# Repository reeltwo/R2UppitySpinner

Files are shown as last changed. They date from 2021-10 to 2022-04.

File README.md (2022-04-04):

# R2 Uppity Spinner

This is the sketch for the R2 Uppity Spinner. It depends on the Reeltwo library. You can download the latest release of the Reeltwo library here: https://github.com/reeltwo/Reeltwo/releases

Uppity Spinner (https://vimeo.com/558277516)

Default baud rate is 9600 baud and the default I2C address is 32 (0x20). Both can be changed using the configuration commands below.

After installing your board you should run the `#PSC` calibration command.

If you want a snappy hyper caffinated periscope you should use a 6V lifter motor. If you want a slower more deliberate periscope you should use a 12V lifter motor.

# Assembling R2 Uppity Spinner PCB Part 1
Part1 (https://www.youtube.com/watch?v=x4_3irdV4C8)

# Assembling R2 Uppity Spinner PCB Part 2
Part2 (https://www.youtube.com/watch?v=MdSRJsYx1T8)

## Configure commands

`#PSC`:
Calibration routine. Will store results in EEPROM if successful
*Examples*:

    #PSC

`#PZERO`:
Erase all stored sequences from EEPROM
*Examples*:

    #PZERO

`#PL`:
List all stored sequences
*Examples*:

    #PL

`#PD`[number]:
Delete numbered sequence from EEPROM
*Examples*:

    #PD0 (delete sequence 0)

`#PS`[number]:seq
Store specified sequence (seq) as number in EEPROM.
*Examples*:

	#PS1:H                        (periscope down)
	#PS2:P100                     (periscope up)
	#PS3:P100:L5:R30              (search light counter-clockwise)
	#PS4:P100,100:L7:M,80,80,2,4  (random fast)
	#PS5:P100:L7:M,50,40,5,5      (random slow)
	#PS6:A0                       (face forward)
	#PS7:P100:L5:R-30             (search light clockwise)
	#PS8:H:P50:W2:P85,35:A90,25:W2:A270,20,100:W2:P100,100:L5:R50:W4:H    (sneaky periscope)
	#PS0:H:L0:P100,5:W2:P50:W2:P85,35:A90,25:W2:A270,20,100:W2:P100,100:L5:R50:W4:H

`#PBAUD`[baudrate]
Change system baudrate. Settings will be stored in EEPROM and take affect once the board is reset.
*Examples*:

	#PBAUD9600               (set baud rate to 9600)

`#PI2C`[address]
Change system I2C address. Settings will be stored in EEPROM and take affect once the board is reset.
*Examples*:

	#PI2C128                 (set I2C address to 128)

`#PR`
Enable/disable rotary unit. This will reboot the board. The setting will persist between reboots.
*Examples*:

	#PR (toggle rotary unit on/off)

`#PNCL`
Set lifter limit switch to normally closed. Default setting.
*Examples*:

	#PNCL (lifter limit normally closed)

`#PNOL`
Set lifter limit switch to normally open.
*Examples*:

	#PNOL (lifter limit normally open)

`#PNCR`
Set rotary limit switch to normally closed. Default setting.
*Examples*:

	#PNCL (rotary limit normally closed)

`#PNOR`
Set rotary limit switch to normally open.
*Examples*:

	#PNOR (rotary limit normally open)

Lifter commands
===============

A lifter command starts with ':P' followed by one of the these. Multiple commands can be issued seperated by a colon. Only the first command needs to be prefixed with 'P':

	:PP100:W2:P0

Would raise the periscope. Wait 2 seconds. Lower the periscope. Separately the commnads would be:

	:PP100
	:PW2
	:PP0

### Play stored sequence

`S`[number]:
Sequences can be stored using #PS
*Examples*:

    #PS0:H:L0:P100,5:W2:P50,25:W2:P85,35:A90,20:W2:A270,20,100:W2:P100,100:L5:R50:W4:H

### Wait number of seconds
`W`[R]seconds:
Wait for specified number of seconds. If 'R' is specified it will randomize the wait time in the range of 1..seconds. 'seconds' is a number between 1 and 600.
*Examples*:

	:PW2    (wait 2 seconds before executing next sequence)
	:PWR    (wait random 1-6 seconds)
	:PWR10  (wait random 1-10 seconds)

### Light kit sequence
`L`number:
Light kit sequence where number is in the range 0..7

`0`: Full Cycle (default): This routine will randomly select the LED color, pattern, and speed for a random period of time.
    
`1`: Off: This setting turns ALL lights OFF. I added this to allow a microcontroller to turn off the lights without having to kill the supply power.
    
`2`: Obi Wan: The Top LED’s flash Blue, the Side LED’s are Blue, and the Main White LED’s are Random.
    
`3`: Yoda: The Top LED’s and Side LED’s fade Green On and Off.
    
`4`: Sith: The Top LED’s and Side LED’s flash Red.
    
`5`: Search Light: All LED’s are White, the Center Bright LED is ON.
    
`6`: Dagobah: This is the most screen accurate mode. The Main White LED’s are ON, the side LED’s are White, the Lower  Rectangular Red LED’s are All On, and the Rear LED’s are Blinking Red.
    
`7`: Sparkle: All White LED’s randomly Flash
    
*Examples*:

    :PL0    (full cycle)
    :PL1    (off)

### Home
`H`[speed]:
Rotates the periscope into the home position and lowers the lifter. Will retry once if rotary ends up not in home position.
*Examples*:

	:PH     (go home at minimum power)
	:PH50   (go home at 50% speed)
	:PH100  (go home at 100% speed)

### Rotate scope relative degrees
`D`[R]:
Rotate scope random relative degrees
*Examples*:

	:PDR

`D`[degrees]:
Rotate scope relative degrees positive for counter clockwise and negative for clockwise
*Examples*:

	:PD90       (rotate periscope relative 90 degrees counter clockwise)
	:PD-90      (rotate periscope relative 90 degrees clockwise)

### Rotate scope absolute degrees
`A`[R][,speed][,maxspeed]:
Rotate scope random absolute degrees
*Examples*:

	:PAR

`A`[degrees][,speed][,maxspeed]:
Rotate scope to absolute position degrees. Positive for clockwise and negative for counter clockwise. Optionally specify the speed percentage and maximum speed percentage. By default the speed used is minimum rotary power (20%). The maximum speed defaults to the same value as speed if omitted.
*Examples*:

	:PA90        (rotate periscope to 90 degrees clockwise)
	:PA270       (rotate periscope to 270 degrees clockwise)
	:PA-90       (rotate periscope to 270 degrees clockwise)
	:PA0         (rotate periscope to home position)
	:PA90,20,100 (rotate periscope to 90 degrees starting at 20% speed increasing to 100%)
	             (will mostly likely overshoot target)

### Rotate scope continously
`R`[speed]:
Spin rotary scope at specified speed percentage
*Examples*:

	:PR30       (spin periscope at 30% speed counter clockwise)
	:PR-30      (spin periscope at 30% speed clockwise)

`R`[,speed]:
Lift periscope to random position.
*Examples*:

	:PPR        (random position)
	:PPR,50     (random position at 50% speed)

### Raise/lower periscope
`P`[position][,speed]:
Lift periscope to specified position percentage.
*Examples*:

	:PP100      (raise periscope fully)
	:PP0        (lower periscope fully)
	:PP50       (raise periscope halfway)
	:PP100,100  (raise periscope fully at maximum speed)

### Movement Random Continous
`M`,lifterspeed][,rotaryspeed][,mininterval][,maxinterval]:
Animate periscope continously rotate/lift.
*Examples*:

	:M,80,80,2,4  (animate lifter 80% power, rotatary random(20%-80%), minimum interval 2 seconds for a duration of 2+random(4) seconds )
	:M,50,40,5,5  (animate lifter 50% power, rotatary random(20%-40%) power, 80% minimum interval 5 seconds for a duration of 5+5 seconds )

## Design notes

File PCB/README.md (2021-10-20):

# Electronics Design

The files were created using Fusion 360, which uses a new version of the Eagle format.

- LifterPCB.brd
- LifterPCB.sch

- RotaryPCB.brd
- RotaryPCB.sch

These files were exported in Eagle v9 compatible format.

- LifterPCB_v9.brd
- LifterPBC_v9.sch

- RotaryPCB_v9.brd
- RotaryPCB_v9.sch

This version uses thicker traces and adds a copper pour. The lifter board is a four layer board. The order of the connection pins on the rotary has changed. Do NOT use the same cable as the older board. The order was changed to allow using a silicone ribbon cable and this crimp connector:

https://www.mouser.com/ProductDetail/571-2-1761607-3

The 10 Wire silicone cable:
https://www.adafruit.com/product/3890

The dual row IDC female connectors:
https://www.amazon.com/gp/product/B07S1NFG4S

If you do not plan on using the ribbon cable there is no need to switch to this version of the lifter.

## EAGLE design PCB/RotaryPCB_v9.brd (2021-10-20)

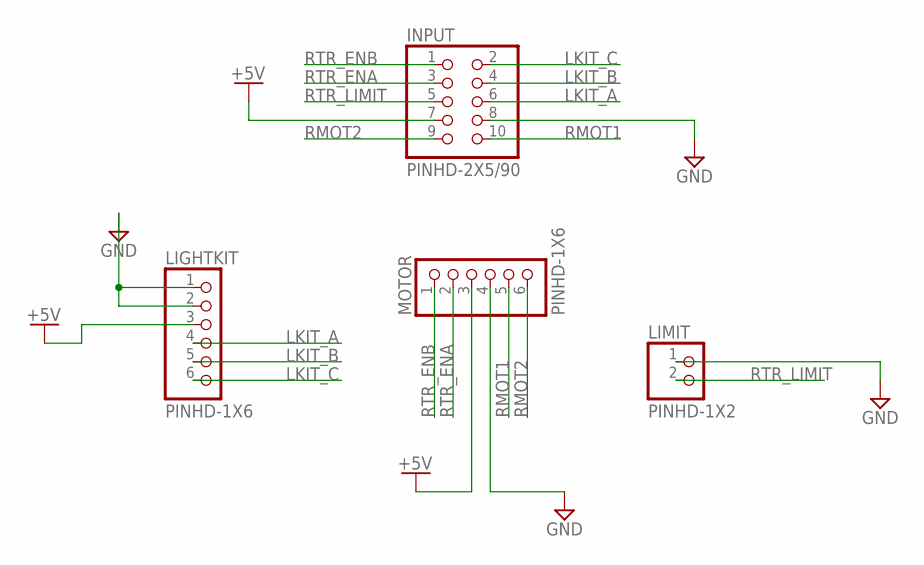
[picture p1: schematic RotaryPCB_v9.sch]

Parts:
INPUT: PINHD-2X5/90; 2X05/90
LIGHTKIT: PINHD-1X6; 1X06
LIMIT: PINHD-1X2; 1X02
MOTOR: PINHD-1X6; 1X06

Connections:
+5V: INPUT.7, LIGHTKIT.3, MOTOR.3
GND: INPUT.8, LIGHTKIT.1, LIGHTKIT.2, LIMIT.1, MOTOR.4
LKIT_A: INPUT.6, LIGHTKIT.4
LKIT_B: INPUT.4, LIGHTKIT.5
LKIT_C: INPUT.2, LIGHTKIT.6
RMOT1: INPUT.10, MOTOR.5
RMOT2: INPUT.9, MOTOR.6
RTR_ENA: INPUT.3, MOTOR.2
RTR_ENB: INPUT.1, MOTOR.1
RTR_LIMIT: INPUT.5, LIMIT.2

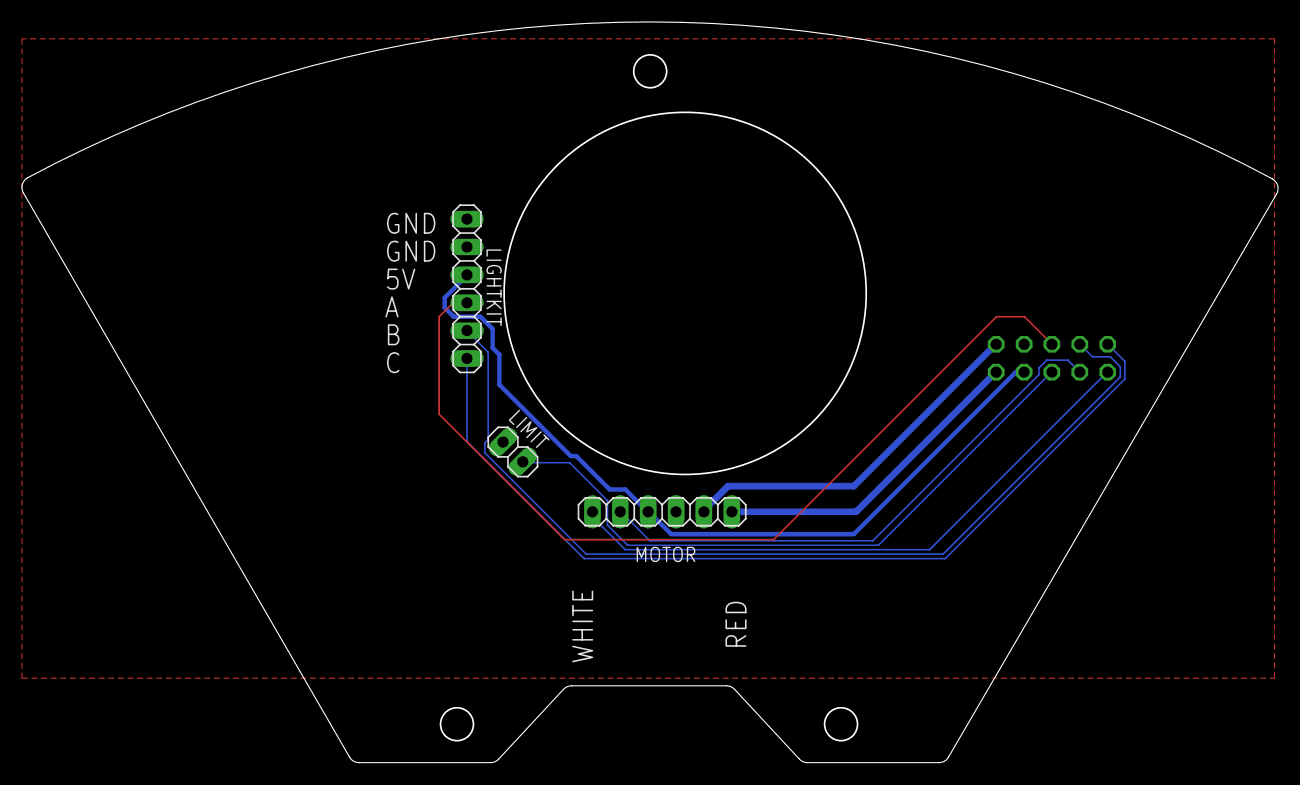
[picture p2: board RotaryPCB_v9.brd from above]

Board: 2 copper layers, 114.5 x 67.5 mm, 4 parts (1 on the bottom side), 10 nets.

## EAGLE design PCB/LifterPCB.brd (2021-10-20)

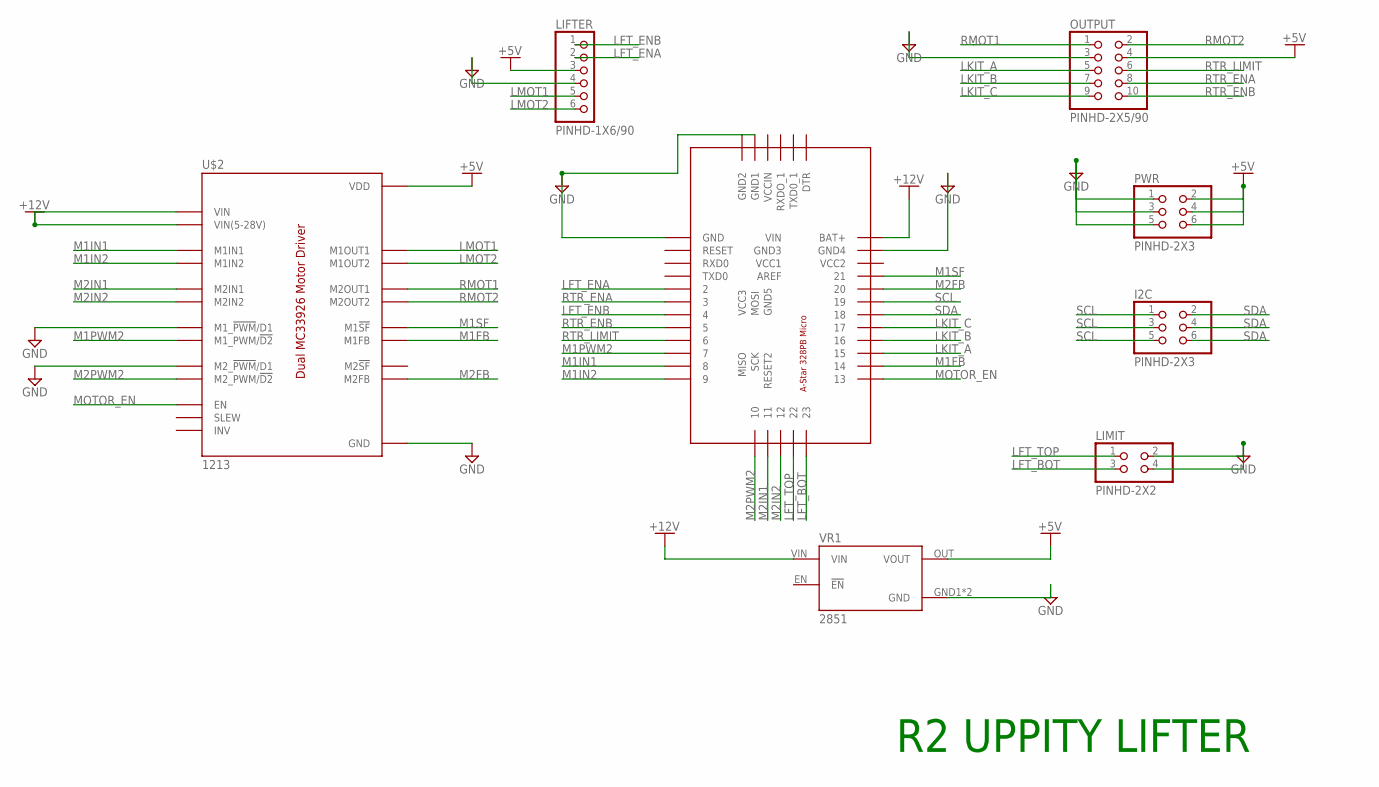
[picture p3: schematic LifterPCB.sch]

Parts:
I2C: PINHD-2X3; 2X03
LIFTER: PINHD-1X6/90; 1X06/90
LIMIT: PINHD-2X2; 2X02
OUTPUT: PINHD-2X5/90; 2X05/90
PWR: PINHD-2X3; 2X03
U$1: POLOLU3161
U$2: 1213
VR1: 2851; VREG_2851

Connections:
+5V: LIFTER.3, OUTPUT.4, PWR.2, PWR.4, PWR.6, U$2.VDD, U$2.VDD$1 (VDD), U$2.VDD$2 (VDD), U$2.VDD$3 (VDD), U$2.VDD$4 (VDD), U$2.VDD$5 (VDD), VR1.OUT (VOUT)
+12V: U$1.BAT+, U$2.MVIN (VIN(5-28V)), U$2.VIN, VR1.VIN
GND: LIFTER.4, LIMIT.2, LIMIT.4, OUTPUT.3, PWR.1, PWR.3, PWR.5, U$1.GND2 (GND4), U$1.GND4 (GND2), U$1.GND5 (GND1), U$1.GND6 (GND), U$2.GND, U$2.GND$1 (GND), U$2.GND$2 (GND), U$2.M1PWM1 (M1_!PWM!/D1), U$2.M2PWM1 (M2_!PWM!/D1), U$2.MGND (GND), VR1.GND1 (GND), VR1.GND2 (GND)
LFT_BOT: LIMIT.3, U$1.23
LFT_ENA: LIFTER.2, U$1.2
LFT_ENB: LIFTER.1, U$1.4
LFT_TOP: LIMIT.1, U$1.22
LKIT_A: OUTPUT.5, U$1.15
LKIT_B: OUTPUT.7, U$1.16
LKIT_C: OUTPUT.9, U$1.17
LMOT1: LIFTER.5, U$2.M1OUT1
LMOT2: LIFTER.6, U$2.M1OUT2
M1FB: U$1.14, U$2.M1FB
M1IN1: U$1.8, U$2.M1IN1
M1IN2: U$1.9, U$2.M1IN2
M1PWM2: U$1.7, U$2.M1PWM2 (M1_PWM/!D2)
M1SF: U$1.21, U$2.M1SF (M1!SF)
M2FB: U$1.20, U$2.M2FB
M2IN1: U$1.11$1 (11), U$2.M2IN1
M2IN2: U$1.12$1 (12), U$2.M2IN2
M2PWM2: U$1.10, U$2.M2PWM2 (M2_PWM/!D2)
MOTOR_EN: U$1.13$1 (13), U$2.EN
RMOT1: OUTPUT.1, U$2.M2OUT1
RMOT2: OUTPUT.2, U$2.M2OUT2
RTR_ENA: OUTPUT.8, U$1.3
RTR_ENB: OUTPUT.10, U$1.5
RTR_LIMIT: OUTPUT.6, U$1.6
SCL: I2C.1, I2C.3, I2C.5, U$1.19
SDA: I2C.2, I2C.4, I2C.6, U$1.18

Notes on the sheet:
R2 UPPITY LIFTER

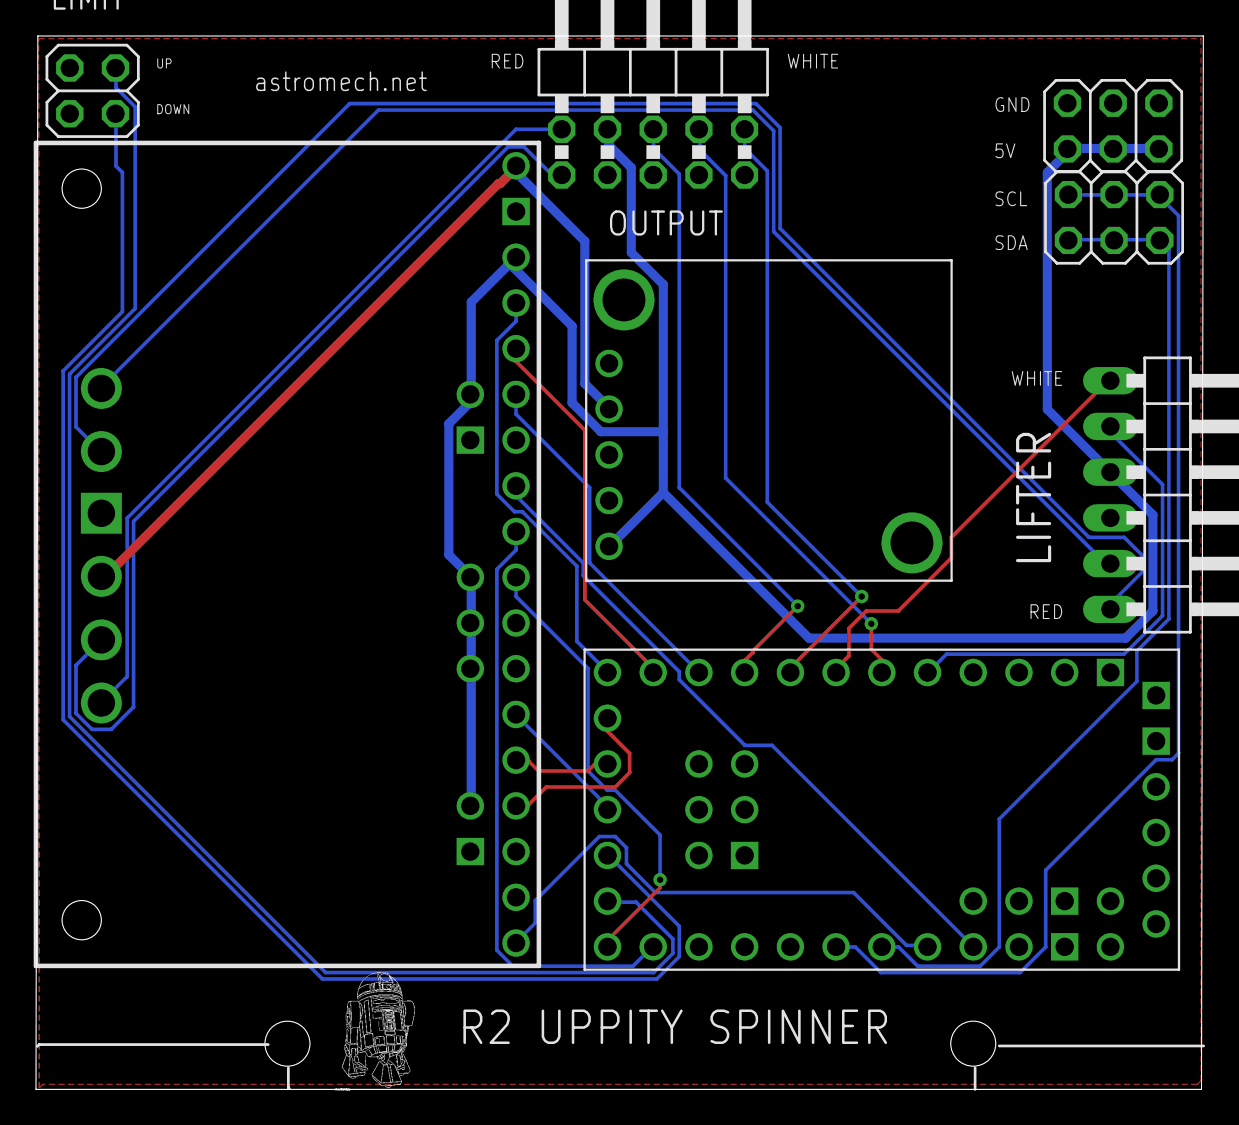
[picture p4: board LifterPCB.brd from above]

Board: 4 copper layers, 64.9 x 58.5 mm, 8 parts (0 on the bottom side), 29 nets.

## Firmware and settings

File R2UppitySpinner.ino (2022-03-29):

//#define USE_DEBUG
#include "ReelTwo.h"
#include "core/SetupEvent.h"
#include "core/Enthropy.h"

///////////////////////////////////
// CONFIGURABLE OPTIONS
///////////////////////////////////

// If debug is enabled the serial baud rate will be 57600
#define SERIAL_BAUD_RATE                    9600
#define I2C_ADDRESS                         0x20
#define CONSOLE_BUFFER_SIZE                 300
#define COMMAND_BUFFER_SIZE                 256
#define ROTARY_THROTTLE_ACCELERATION_SCALE  100
#define ROTARY_THROTTLE_DECELERATION_SCALE  20
#define ROTARY_THROTTLE_LATENCY             25
#define ROTARY_FUDGE_POSITION               5

// Default random duration of 'M' movement mode
#define MOVEMODE_MIN_DURATION               30      // minimum 30 seconds
#define MOVEMODE_MAX_DURATION               30      // random range additional 30 seconds
#define MOVEMODE_MAX_INTERVAL               5       // default interval between random commands

///////////////////////////////////
// RISKIER CONFIGURATION OPTIONS
///////////////////////////////////

// IA-Parts lifter defaults
#define LIFTER_MINIMUM_POWER        45      // 40 out of 100. Don't bother with lower values. Won't lift reliably
#define LIFTER_SEEKBOTTTOM_POWER    30      // 30 out of 100. Lower than LIFTER_MINIMUM_POWER because we are going down
#define ROTARY_MINIMUM_POWER        20      // 20 out of 100. Don't bother with lower values. Won't rotate reliably
#define LIFTER_DISTANCE             845     // default value - lifter will calibrate

// Greg Hulette’s Periscope Lifter
//#define LIFTER_MINIMUM_POWER        65      // 65 out of 100. Don't bother with lower values. Won't lift reliably
//#define LIFTER_SEEKBOTTTOM_POWER    40      // 40 out of 100. Lower than LIFTER_MINIMUM_POWER because we are going down
//#define ROTARY_MINIMUM_POWER        40      // 40 out of 100. Don't bother with lower values. Won't rotate reliably
//#define LIFTER_DISTANCE             1200     // default value 1200 - lifter will calibrate

#define ROTARY_MINIMUM_HEIGHT       LIFTER_DISTANCE/2
#define MOTOR_TIMEOUT               2000
#define OUTPUT_LIMIT_PRESCALE       3.1
#define DISTANCE_OUTPUT_SCALE       3
#define MAX_COMMANDS                100

#define EEPROM_MAGIC                0xba5eba11
#define EEPROM_CMD_MAGIC            0xf005ba11
#define EEPROM_END_TAG              0xff

///////////////////////////////////
// This option is for builders working on their own custom lifters.
// It will leave the lifter logic intact but act as if there is no rotary.
///////////////////////////////////
//#define DISABLE_ROTARY
///////////////////////////////////

#ifdef DISABLE_ROTARY
// DO NOT ENABLE THIS UNLESS YOU REMOVE THE ROTARY UNIT
#define DISABLE_SAFETY_MANEUVER
#endif

///////////////////////////////////
// --- Lifter mechanism

#define PIN_LIFTER_ENCODER_A   2
#define PIN_LIFTER_ENCODER_B   4

#define PIN_M1SF               A7
#define PIN_M2FB               A6

#define PIN_LIFTER_TOPLIMIT    23
#define PIN_LIFTER_BOTLIMIT    22

/* Lifter Motor */
#define PIN_MOTORS_EN          13   /* also BUILTIN_LED */
#define PIN_M1D2               7
#define PIN_M1PWM1             8
#define PIN_M1PWM2             9
#define PIN_M1FB               A0

///////////////////////////////////
// --- Rotary mechanism

#define PIN_ROTARY_ENCODER_A   3
#define PIN_ROTARY_ENCODER_B   5

#define PIN_ROTARY_LIMIT       6

/* Rotary Motor */
#define PIN_M2D2               10
#define PIN_M2PWM1             11
#define PIN_M2PWM2             12

//////////////////////////////
// LIGHT KIT TRI-STATE
//////////////////////////////
//   A    B    C
// OPEN OPEN OPEN  (Switch Position 0): Full Cycle (default): This routine will randomly select the LED
//                                      color, pattern, and speed for a random period of time.
// OPEN OPEN GND   (Switch Position 1): Off: This setting turns ALL lights OFF. I added this to allow a
//                                      microcontroller to turn off the lights without having to kill
//                                      the supply power.
// OPEN GND  OPEN  (Switch Position 2): Obi Wan: The Top LED’s flash Blue, the Side LED’s are Blue,
//                                      and the Main White LED’s are Random.
// OPEN GND  GND   (Switch Position 3): Yoda: The Top LED’s and Side LED’s fade Green On and Off.
// GND  OPEN OPEN  (Switch Position 4): Sith: The Top LED’s and Side LED’s flash Red.
// GND  OPEN GND   (Switch Position 5): Search Light: All LED’s are White, the Center Bright LED is ON.
// GND  GND  OPEN  (Switch Position 6): Dagobah: This is the most screen accurate mode.
//                                      The Main White LED’s are ON, the side LED’s are White, the Lower 
//                                      Rectangular Red LED’s are All On, and the Rear LED’s are Blinking Red.
// GND GND GND     (Switch Position 7): Sparkle: All White LED’s randomly Flash

#define PIN_LIGHTKIT_A         A1
#define PIN_LIGHTKIT_B         A2
#define PIN_LIGHTKIT_C         A3

///////////////////////////////////
// SDA A4
// SCL A5

#ifdef I2C_ADDRESS
#include <Wire.h>
#endif
#include <EEPROM.h>

///////////////////////////////////

#include "drive/TargetSteering.h"

///////////////////////////////////
#define ENCODER_STATUS_RATE 200 // ms (10Hz)

struct OutputLimit
{
    bool valid;
    unsigned outputLimit;
};

OutputLimit sUpLimits[100/5+1];
OutputLimit sDownLimits[100/5+1];
unsigned sMinimumPower;
unsigned sLifterDistance = LIFTER_DISTANCE;
bool sUpLimitsCalibrated;
bool sDownLimitsCalibrated;
bool sSafetyManeuver;
bool sCalibrating;
bool sDisableRotary;
uint8_t sI2CAddress = I2C_ADDRESS;
uint32_t sBaudRate = SERIAL_BAUD_RATE;
unsigned sRotaryCircleEncoderCount;

static bool sNextCommand;
static bool sProcessing;
static unsigned sPos;
static uint32_t sWaitNextSerialCommand;
static char sBuffer[CONSOLE_BUFFER_SIZE];
static bool sCmdNextCommand;
static char sCmdBuffer[COMMAND_BUFFER_SIZE];

static void runSerialCommand()
{
    sWaitNextSerialCommand = 0;
    sProcessing = true;
}

static void resetSerialCommand()
{
    sWaitNextSerialCommand = 0;
    sNextCommand = false;
    sProcessing = (sCmdBuffer[0] == ':');
    sPos = 0;
}

///////////////////////////////////

class PeriscopeLifter : public SetupEvent
{
public:
    enum
    {
        kLightKit_FullCycle = 0,
        kLightKit_Off = 1,
        kLightKit_ObiWan = 2,
        kLightKit_Yoda = 3,
        kLightKit_Sith = 4,
        kLightKit_SearchLight = 5,
        kLightKit_Dagobah = 6,
        kLightKit_Sparkle = 7
    };

    static void println()
    {
        Serial.println();
    }

    static void print(char num)
    {
        Serial.print(num);
    }

    static void print(int num)
    {
        Serial.print(num);
    }

    static void print(long num)
    {
        Serial.print(num);
    }

    static void print(unsigned int num)
    {
        Serial.print(num);
    }

    static void print(float num)
    {
        Serial.print(num);
    }

    static void print(const char* str)
    {
        Serial.print(str);
    }

    static void print(const __FlashStringHelper* str)
    {
        Serial.print(str);
    }

    static void println(char num)
    {
        Serial.println(num);
    }

    static void println(int num)
    {
        Serial.println(num);
    }

    static void println(long num)
    {
        Serial.println(num);
    }

    static void println(unsigned int num)
    {
        Serial.println(num);
    }

    static void println(float num)
    {
        Serial.println(num);
    }

    static void println(const char* str)
    {
        Serial.println(str);
    }

    static void println(const __FlashStringHelper* str)
    {
        Serial.println(str);
    }

    ///////////////////////////////////
    // Read limit switches
    ///////////////////////////////////

    static bool lifterTopLimit()
    {
        bool limit = (digitalRead(PIN_LIFTER_TOPLIMIT) == fLifterLimitSetting);
        return limit;
    }

    static bool lifterBottomLimit()
    {
        bool limit = (digitalRead(PIN_LIFTER_BOTLIMIT) == fLifterLimitSetting);
        return limit;
    }

    static long getLifterPosition()
    {
        long pos;
        cli();
        pos = encoder_lifter_ticks;
        sei();
        return pos;
    }

    ///////////////////////////////////

    static bool rotaryHomeLimit()
    {
    #ifdef DISABLE_ROTARY
        // No rotary unit. Always in home position
        return true;
    #else
        bool limit = sDisableRotary || (digitalRead(PIN_ROTARY_LIMIT) == fRotaryLimitSetting);
        return limit;
    #endif
    }

    static long getRotaryPosition()
    {
        long pos;
        cli();
        pos = encoder_rotary_ticks;
        sei();
        return pos;
    }

    ///////////////////////////////////

    static bool lifterMotorFault()
    {
        return !digitalRead(PIN_M1SF);
    }

    static int lifterMotorCurrent()
    {
        // 5V / 10bit resolution / 0.525V/A = 0.0093006 A/count ~= 93 mA/count
        return analogRead(PIN_M1FB) * 93;
    }

    static int rotaryMotorCurrent()
    {
        // 5V / 10bit resolution / 0.525V/A = 0.0093006 A/count ~= 93 mA/count
        return analogRead(PIN_M2FB) * 93;
    }

    static bool isIdle()
    {
        if (lifterBottomLimit())
        {
            if (!fMotorsEnabled ||
                fMotorsEnabledTime + MOTOR_TIMEOUT < millis())
            {
                return true;
            }
        }
        return false;
    }

    ///////////////////////////////////

    static bool motorsEnabled()
    {
        return fMotorsEnabled;
    }

    static void disableMotors()
    {
        digitalWrite(PIN_MOTORS_EN, LOW);
        digitalWrite(PIN_M1D2, LOW);
        digitalWrite(PIN_M2D2, LOW);
        fMotorsEnabled = false;
    }

    static void enableMotors()
    {
        digitalWrite(PIN_MOTORS_EN, HIGH);
        fMotorsEnabled = true;
        fMotorsEnabledTime = millis();
    }

    ///////////////////////////////////
    // Move lifter motor up/down
    ///////////////////////////////////

    static void lifterMotorMove(float throttle)
    {
        bool reverse = (throttle < 0);
        throttle = min(max(abs(throttle), 0.0f), 1.0f);

        if (throttle < 0.10)
            throttle = 0;
        if (fLifterThrottle != throttle)
        {
            enableMotors();
            if (reverse)
            {
                analogWrite(PIN_M1PWM1, 255);
                analogWrite(PIN_M1PWM2, 255 - (255 * throttle));
                fLifterThrottle = -throttle;
            }
            else
            {
                analogWrite(PIN_M1PWM1, 0);
                analogWrite(PIN_M1PWM2, 255 * throttle);
                fLifterThrottle = throttle;
            }
            digitalWrite(PIN_M1D2, HIGH);
        }
    }

    static void lifterMotorStop()
    {
        enableMotors();
        analogWrite(PIN_M1PWM1, 0);
        analogWrite(PIN_M1PWM2, 0);
        digitalWrite(PIN_M1D2, HIGH);
        fLifterThrottle = 0;
    }

    static void lifterMotorOff()
    {
        digitalWrite(PIN_M1D2, LOW);
    }

    ///////////////////////////////////

    static bool serialAbort()
    {
        if (sCalibrating && Serial.available())
        {
            DEBUG_PRINTLN("SERIAL ABORT");
            while (Serial.available())
                Serial.read();
            sCalibrating = false;
            return true;
        }
        return false;
    }

    static bool seekToPosition(float pos, float speed)
    {
        if (!ensureSafetyManeuver())
            return false;

        // ensure position is in the range of 0.0 [bottom] - 1.0 [top]
        pos = min(max(abs(pos), 0.0f), 1.0f);
        if (isRotarySpinning() || !rotaryHomeLimit())
        {
            // Cannot go below 50% if spinning or not at home position
            pos = min(max(pos, 0.5f), 1.0f);
        }
        if (speed * 100 < sMinimumPower)
            return seekToPositionSlow(pos, speed/(sMinimumPower/100.0));

        long maxlen = sLifterDistance;
        long current = getLifterPosition();
        long target_ticks = pos * maxlen;

        long distance = abs(target_ticks - current);
        TargetSteering steering(target_ticks);
        steering.setSampleTime(1);
        float minpower = (1.0f - ((float)distance / (float)maxlen)) + 0.1;
        steering.setDistanceTunings(1.0, minpower, minpower);

        float limit;
        bool success = false;
        if (target_ticks > getLifterPosition())
        {
            // seek up
            if (!getUpOutputLimit(speed, limit))
                return false;
            steering.setDistanceOutputLimits(min(distance * DISTANCE_OUTPUT_SCALE, limit));
            bool topLimit;
            LifterStatus lifterStatus;
            for (;;)
            {
                long encoder_ticks = getLifterPosition();
                topLimit = lifterTopLimit();
                if (topLimit || encoder_ticks == target_ticks || serialAbort())
                    break;
                steering.setCurrentDistance(encoder_ticks);
                lifterMotorMove(steering.getThrottle() * speed);

                if (!lifterStatus.isMoving())
                {
                    DEBUG_PRINTLN(F("ABORT"));
                    break;
                }
            }
            success = topLimit;
        }
        else
        {
            // seek down
            if (!getDownOutputLimit(speed, limit))
                return false;
            steering.setDistanceOutputLimits(min(distance * DISTANCE_OUTPUT_SCALE, limit));
            bool botLimit;
            LifterStatus lifterStatus;
            for (;;)
            {
                long encoder_ticks = getLifterPosition();
                botLimit = lifterBottomLimit();
                if (botLimit || encoder_ticks == target_ticks || serialAbort())
                    break;
                steering.setCurrentDistance(encoder_ticks);
                lifterMotorMove(steering.getThrottle() * speed);

                if (!lifterStatus.isMoving())
                {
                    DEBUG_PRINTLN(F("ABORT"));
                    break;
                }
            }
            success = botLimit;
        }
        lifterMotorStop();
        return success;
    }

    ///////////////////////////////////
    // Spin rotary motor left/right
    ///////////////////////////////////

    static bool rotaryAllowed()
    {
    #ifdef DISABLE_ROTARY
        // Rotary motion not allowed
        return false;
    #else
        return !sDisableRotary && (getLifterPosition() > ROTARY_MINIMUM_HEIGHT);
    #endif
    }

    static void rotaryMotorSpeed(float speed)
    {
        fRotarySpeed = (rotaryAllowed()) ? speed : 0;
        fRotaryEncoderLastStatus = millis();
        rotaryMotorUpdate();
    }

    static void rotaryMotorUpdate()
    {
    #ifndef DISABLE_ROTARY
        if (sDisableRotary)
            return;
        uint32_t currentMillis = millis();
        if (currentMillis - fRotaryThrottleUpdate > ROTARY_THROTTLE_LATENCY)
        {
            if (rotaryAllowed() && (fRotarySpeed != 0 || fRotaryThrottle != 0))
            {
                float throttle = 0;
                long encoder_ticks = getRotaryPosition();
                if (fRotarySpeed > fRotaryThrottle)
                {
                    float scale = ROTARY_THROTTLE_ACCELERATION_SCALE;
                    if (fRotaryThrottle < 0)
                        scale = ROTARY_THROTTLE_DECELERATION_SCALE;
                    float val = max(abs(fRotarySpeed - fRotaryThrottle) / scale, 0.01f);
                    throttle = ((int)round(min(fRotaryThrottle + val, fRotarySpeed)*100))/100.0f;
                    DEBUG_PRINTLN(throttle);
                    rotaryMotorMove(throttle);
                    fRotaryThrottle = throttle;
                }
                else if (fRotarySpeed < fRotaryThrottle)
                {
                    float scale = ROTARY_THROTTLE_ACCELERATION_SCALE;
                    if (fRotaryThrottle > 0)
                        scale = ROTARY_THROTTLE_DECELERATION_SCALE;
                    float val = abs(fRotarySpeed - fRotaryThrottle) / scale;
                    throttle = ((int)floor(max(fRotaryThrottle - val, fRotarySpeed)*100))/100.0f;
                    DEBUG_PRINTLN(throttle);
                    rotaryMotorMove(throttle);
                    fRotaryThrottle = throttle;
                }
                if (millis() - fRotaryEncoderLastStatus > ENCODER_STATUS_RATE*2)
                {
                    fRotaryEncoderLastStatus = millis();
                    if (fRotaryEncoderLastTick == encoder_ticks)
                    {
                        DEBUG_PRINTLN(F("ROTARY NOT MOVING - ABORT"));
                        rotaryMotorStop();
                    }
                    fRotaryEncoderLastTick = encoder_ticks;
                }
                fRotaryThrottleUpdate = currentMillis;
            }
        }
    #endif
    }

    static void rotaryMotorMove(float throttle)
    {
    #ifndef DISABLE_ROTARY
        if (sDisableRotary)
            return;
        bool reverse = (throttle < 0);
        throttle = min(max(abs(throttle), 0.0f), 1.0f);
        if (throttle < 0.10)
            throttle = 0;
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
void loop()
{
#ifdef I2C_ADDRESS
    handleI2CEvent();
#endif
    lifter.animate();

    // append commands to command buffer
    if (Serial.available())
    {
        int ch = Serial.read();
        if (ch == 0x0A || ch == 0x0D)
        {
            runSerialCommand();
        }
        else if (sPos < SizeOfArray(sBuffer)-1)
        {
            sBuffer[sPos++] = ch;
            sBuffer[sPos] = '\0';
        }
    }
    if (sProcessing && millis() > sWaitNextSerialCommand)
    {
        if (sCmdBuffer[0] == ':')
        {
            char* end = strchr(sCmdBuffer+1, ':');
            if (end != nullptr)
                *end = '\0';
            if (!processCommand(sCmdBuffer, !sCmdNextCommand))
            {
                // command invalid abort buffer
                DEBUG_PRINT(F("Unrecognized: ")); DEBUG_PRINTLN(sCmdBuffer);
                sWaitNextSerialCommand = 0;
                end = nullptr;
            }
            if (end != nullptr)
            {
                *end = ':';
                strcpy(sCmdBuffer, end);
                DEBUG_PRINT(F("REMAINS: "));
                DEBUG_PRINTLN(sCmdBuffer);
                sCmdNextCommand = true;
            }
            else
            {
                sCmdBuffer[0] = '\0';
                sCmdNextCommand = false;
            }
        }
        else if (sBuffer[0] == ':')
        {
            char* end = strchr(sBuffer+1, ':');
            if (end != nullptr)
                *end = '\0';
            if (!processCommand(sBuffer, !sNextCommand))
            {
                // command invalid abort buffer
                DEBUG_PRINT(F("Unrecognized: ")); DEBUG_PRINTLN(sBuffer);
                sWaitNextSerialCommand = 0;
                end = nullptr;
            }
            if (end != nullptr)
            {
                *end = ':';
                strcpy(sBuffer, end);
                sPos = strlen(sBuffer);
                DEBUG_PRINT(F("REMAINS: "));
                DEBUG_PRINTLN(sBuffer);
                sNextCommand = true;
            }
            else
            {
                resetSerialCommand();
                sBuffer[0] = '\0';
            }
        }
        else
        {
            processCommand(sBuffer, true);
            resetSerialCommand();
        }
    }
    if (lifter.isIdle() && lifter.motorsEnabled())
    {
        DEBUG_PRINTLN("DISABLE MOTORS");
        lifter.disableMotors();
    }
    static bool sHome;
    if (sHome != lifter.rotaryHomeLimit())
    {
        sHome = lifter.rotaryHomeLimit();
        if (sHome)
            Serial.println("HOME");
    }
#ifdef USE_DEBUG
    static bool sLastTop;
    static bool sLastBot;
    static bool sLastRot;
    static long sLastLifter;
    static long sLastRotary;
    if (sLastTop != lifter.lifterTopLimit() ||
        sLastBot != lifter.lifterBottomLimit() ||
        sLastRot != lifter.rotaryHomeLimit() ||
        sLastLifter != lifter.getLifterPosition() ||
        sLastRotary != lifter.getRotaryPosition())
    {
        sLastTop = lifter.lifterTopLimit();
        sLastBot = lifter.lifterBottomLimit();
        sLastRot = lifter.rotaryHomeLimit();
        sLastLifter = lifter.getLifterPosition();
        sLastRotary = lifter.getRotaryPosition();
        DEBUG_PRINT(F("T: ")); DEBUG_PRINT(sLastTop);
        DEBUG_PRINT(F(" B: ")); DEBUG_PRINT(sLastBot);
        DEBUG_PRINT(F(" R: ")); DEBUG_PRINT(sLastRot);
        DEBUG_PRINT(F(" H: ")); DEBUG_PRINT(sLastLifter/float(sLifterDistance)*100.0);
        DEBUG_PRINT(F(" D: ")); DEBUG_PRINT(lifter.rotaryMotorCurrentPosition());
        DEBUG_PRINT(F(" P: ")); DEBUG_PRINT(lifter.getRotaryPosition());
        DEBUG_PRINT(F(" F: ")); DEBUG_PRINT(lifter.lifterMotorFault());
        DEBUG_PRINTLN();
    }
#endif
}

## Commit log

2021-06-02 Added board files
    [LifterPCB.brd, LifterPCB.sch, RotaryPCB.brd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]
2021-06-02 Added configuration commands #PBAUD and #PI2C to set the baudrate and I2C address
2021-06-10 Generalized the motor stall detection and added to all loops. Fixed homing sequence to be more reliable. Added enthropy to random numbers.
    [R2UppitySpinner.ino]
2021-06-11 Latest version of Eagle board files plus Eagle v9 version
    [LifterPCB_v9.brd, LifterPCB_v9.sch, RotaryPCB.brd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]
2021-06-27 Added commands PNCL, PNOL, PNCR, and PNOR. To change the type of limit switch wiring. Normally the limit switches should be wired NC. Meaning that digitalRead() will return 0 if the limit switch is t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
2021-08-27 Improved calibration routine
2021-09-14 Fixed listing of stored sequences
    [R2UppitySpinner.ino]
2021-10-20 Added support for DISABLE_ROTARY for builders making their own custom lifters. Fixed support for I2C IA-Parts style commands.
    [R2UppitySpinner.ino]
2021-10-20 This version uses thicker traces and adds a copper pour. The lifter board is a four layer board. The order of the connection pins on the rotary has changed. Do NOT use the same cable as the older boa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
    [LifterPCB.brd, LifterPCB.sch, LifterPCB_v9.brd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]
2022-01-20 Update README.md
    Added video links showing assembly of PCB
2022-03-29 Fixed bug in rotate relative which would only rotate in one direction because it normalized the parameter. Simplified the code so the relative rotation just calls the absolute rotation code after cal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
    [R2UppitySpinner.ino]
2022-03-29 Lifter wouldn't lifter slower than minimum power and never called seekToPositionSlow()
